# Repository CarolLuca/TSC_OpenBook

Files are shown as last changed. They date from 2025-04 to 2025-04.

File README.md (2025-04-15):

# OpenBook

## Introduction

OpenBook is an energy-efficient e-book reader designed with open-source principles, featuring Wi-Fi connectivity and environmental sensing capabilities. The device emphasizes a minimalist design, providing a distraction-free reading experience through a high-contrast e-paper display that mimics real paper, reducing eye strain during extended reading sessions.

## Block Diagram

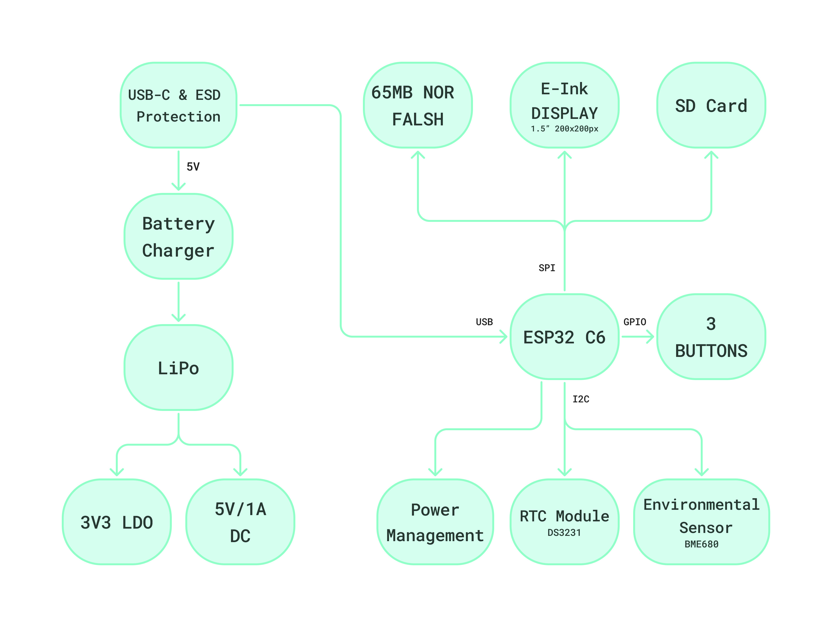
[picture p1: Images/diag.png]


## Hardware Description

### Microcontroller

The OpenBook is built around the **ESP32-C6-WROOM-1-N8** microcontroller:
- 32-bit RISC-V single-core processor running at up to 160MHz
- 320KB ROM, 512KB HP SRAM, 16KB LP SRAM
- Built-in Wi-Fi 6 and Bluetooth LE 5.0 connectivity
- Support for various interfaces: GPIO, SPI, UART, I2C, PWM
- Operating voltage: 3.3V

The ESP32-C6 offers excellent power efficiency with multiple power modes:
- Active mode: 160-260mA (when running at full capacity)
- Modem sleep: 3-20mA (Wi-Fi radio disabled)
- Light sleep: 0.8mA
- Deep sleep: 10μA (core powered down, wake sources active)
- Hibernation: 2.5μA (minimal functions active)

### Display Interface

The OpenBook connects to a 7.5" E-Paper Display through an FPC connector. The display communicates via SPI:
- EPD_CS connected to ESP32-C6 GPIO10
- EPD_DC connected to ESP32-C6 GPIO5
- EPD_RST connected to ESP32-C6 GPIO23
- EPD_BUSY connected to ESP32-C6 GPIO3
- MOSI, SCK shared with SD card interface

The e-paper display was chosen for its paper-like appearance, ultra-low power consumption (only requires power during page refreshes), and excellent readability in direct sunlight.

### Storage Solutions

The OpenBook features dual storage solutions:

1. **MicroSD Card Interface** (primary storage for e-books):
   - Connected via SPI protocol
   - Card Detect/DAT3 connected to ESP32-C6 GPIO4
   - CMD connected to ESP32-C6 GPIO7 (MOSI for SPI)
   - DAT0 connected to ESP32-C6 GPIO2 (MISO for SPI)
   - CLK connected to ESP32-C6 GPIO6 (SCK for SPI)
   
2. **64MB NOR Flash Memory** (firmware and system storage):
   - Connected via SPI protocol
   - CS connected to ESP32-C6 GPIO11
   - Shares MOSI, MISO, and SCK with the SD card interface
   - Provides reliable non-volatile storage for the operating system and application code

### Real-Time Clock (RTC)

A DS3231SN RTC module maintains accurate timekeeping even when the device is powered off:
- Communicates via I2C protocol
- SCL connected to ESP32-C6 GPIO22
- SDA connected to ESP32-C6 GPIO21
- Reset pin connected to ESP32-C6 GPIO18
- 32KHz output connected to ESP32-C6 GPIO1
- SQW/INT connected to ESP32-C6 GPIO0
- Features a backup battery input for continuous timekeeping
- Temperature-compensated crystal oscillator for high accuracy (+/-2ppm)

### Environmental Sensing

The BME688 environmental sensor provides comprehensive monitoring:
- Digital low-power gas, pressure, temperature, and humidity sensor
- Communicates via I2C (shared bus with RTC)
- SCK connected to ESP32-C6 GPIO22 (SCL for I2C)
- SDI connected to ESP32-C6 GPIO21 (SDA for I2C)
- Control pins connected to ESP32-C6 GPIO19
- Power consumption: 3.7μA at 1Hz sampling rate; 0.15μA in sleep mode
- Temperature range: -40 to +85°C
- Humidity measurement range: 0-100% RH
- Pressure range: 300-1100 hPa

### Power Management

The OpenBook is designed for extended battery life:

1. **USB-C Connector**:
   - Industry-standard charging and data interface
   - Connected to ESP32-C6 via USB lines (GPIO12/GPIO13)
   - ESD protection provided by USBLC6-2SC6Y
   
2. **Li-Po Battery Charging Controller (MCP73831)**:
   - Handles battery charging from USB with programmable charge current
   - Input voltage: 3.75V to 6V
   - Battery output protection circuitry

3. **LDO Voltage Regulator (XC6220A331MR-G)**:
   - Provides stable 3.3V from battery voltage
   - Low quiescent current: 1μA
   - High efficiency operation

4. **Battery Fuel Gauge (MAX17048G+T10)**:
   - Monitors battery charge level using ModelGauge algorithm
   - Communicates via I2C (shared bus with RTC and BME688)
   - SCL connected to ESP32-C6 GPIO22
   - SDA connected to ESP32-C6 GPIO21
   - Power consumption: 23μA active, 3μA hibernate
   - Provides accurate remaining capacity estimation

### User Input

Three physical buttons provide intuitive navigation:
1. **Reset Button**: Connected to ESP32-C6 Enable pin
2. **Boot Button**: Connected to ESP32-C6 GPIO9
3. **Navigation Button**: Connected to ESP32-C6 GPIO15

Each button includes debouncing circuitry to ensure reliable operation.

### Expansion Capability

A Qwiic connector provides expandability:
- Compatible with Stemma QT sensors and modules
- Connects to the I2C bus
- Allows for easy addition of future sensors without soldering

## Pin Allocation of ESP32-C6

| Pin Number | GPIO | Function | Component | Reason for Selection |
|---|---|---|---|---|
| 3 | EN | Reset | Reset Button | Hardware-defined enable pin |
| 8 | GPIO0 | SQW/INT | RTC DS3231SN Interrupt | Allows RTC-based wakeup from sleep |
| 9 | GPIO1 | 32KHz input | RTC DS3231SN 32KHz output | Provides precise timing reference |
| 27 | GPIO2 | MISO | SD Card, E-Paper, NOR Flash | Hardware SPI MISO line |
| 28 | GPIO3 | EPD_BUSY | E-Paper Display busy signal | Status monitoring for display |
| 30 | GPIO4 | SD_CS | SD Card chip select | SPI device selection |
| 31 | GPIO5 | EPD_DC | E-Paper Display data/command | Display controller communication |
| 32 | GPIO6 | SCK | SD Card, E-Paper, NOR Flash | Hardware SPI clock |
| 33 | GPIO7 | MOSI | SD Card, E-Paper, NOR Flash | Hardware SPI MOSI line |
| 13 | GPIO9 | Boot | Boot Button | Boot mode selection |
| 14 | GPIO10 | EPD_CS | E-Paper Display chip select | SPI device selection |
| 15 | GPIO11 | FLASH_CS | NOR Flash chip select | SPI device selection |
| 16 | GPIO12 | USB_D- | USB Data negative | USB communication |
| 17 | GPIO13 | USB_D+ | USB Data positive | USB communication |
| 23 | GPIO15 | Navigation | Navigation Button | User input |
| 16 | GPIO18 | RTC_RST | RTC reset | Reset control for RTC |
| 17 | GPIO19 | I2C_PW | BME688 power control | Power management for sensor |
| 19 | GPIO21 | SDA | I2C data (RTC, BME688, Battery Gauge) | Hardware I2C data line |
| 20 | GPIO22 | SCL | I2C clock (RTC, BME688, Battery Gauge)| Hardware I2C clock line |
| 21 | GPIO23 | EPD_RST | E-Paper Display reset | Display initialization control |

## Bill of Materials (BOM)

| Component | Description | Price (EUR) | Provider | Datasheet |
|---|---|---|---|---|
| ESP32-C6-WROOM-1-N8 | Main Microcontroller | 2.99 | [Mouser](https://eu.mouser.com/ProductDetail/Espressif-Systems/ESP32-C6-WROOM-1U-N8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) | [Datasheet](https://eu.mouser.com/datasheet/2/891/Espressif_Systems_7_11_2023_esp32_c6_wroom_1_wroom-3236277.pdf) |
| USB4110-GF-A | USB-C Connector | 0.39 | [Mouser](https://eu.mouser.com/ProductDetail/Same-Sky/UJC-H-G-SMT-2-P6-TR?qs=IKkN%2F947nfApFV8T6rOqww%3D%3D) | [Datasheet](https://eu.mouser.com/datasheet/2/1628/ujc_h_g_smt_2_p6_tr-3511211.pdf) |
| USBLC6-2SC6Y | USB ESD Protection | 0.44 | [Mouser](https://eu.mouser.com/ProductDetail/STMicroelectronics/USBLC6-2SC6Y?qs=gNDSiZmRJS%2FOgDexvXkdow%3D%3D) | [Datasheet](https://eu.mouser.com/datasheet/2/389/usblc6_2sc6y-1852505.pdf) |
| DMG2305UX-7 | P-Channel MOSFET | 0.19 × 2 | [Mouser](https://eu.mouser.com/ProductDetail/Diodes-Incorporated/DMG2305UX-7?qs=L1DZKBg7t5F%2FNBHrjfxC%252Bg%3D%3D) | [Datasheet](https://www.diodes.com/assets/Datasheets/DMG2305UX.pdf) |
| SD0805S020S1R0 | Schottky Diode | 0.30 × 2 | [Mouser](https://eu.mouser.com/ProductDetail/KYOCERA-AVX/SD0805S020S1R0?qs=jCA%252BPfw4LHbpkAoSnwrdjw%3D%3D) | [Datasheet](https://eu.mouser.com/datasheet/2/40/schottky-3165252.pdf) |
| XC6220A331MR-G | LDO Voltage Regulator | 1.46 | [Mouser](https://eu.mouser.com/ProductDetail/Torex-Semiconductor/XC6220A331MR-G?qs=AsjdqWjXhJ8ZSWznL1J0gg%3D%3D) | [Datasheet](https://eu.mouser.com/datasheet/2/760/xc6220-3371556.pdf) |
| 293D107X9010D2TE3 | Tantalum Capacitor | 0.68 | [Mouser](https://eu.mouser.com/ProductDetail/Vishay-Sprague/293D107X9010D2TE3?qs=8dfOI6wKXonVqFgS8%252BQ%2FMA%3D%3D) | [Datasheet](https://www.vishay.com/docs/40002/293d.pdf) |
| 112A-TAAR-R03 | MicroSD Card Socket | 1.10 | [Comet](https://store.comet.srl.ro/Catalogue/Product/43497/) | [Datasheet](https://store.comet.bg/download-file.php?id=27596) |
| IFDC5050JZER680M | 68µH Power Inductor | 0.90 | [Mouser](https://eu.mouser.com/ProductDetail/Vishay-Dale/IFDC5050JZER680M?qs=iLKYxzqNS745SePZd8tBoA%3D%3D) | [Datasheet](https://www.vishay.com/docs/34635/ifdc5050jz.pdf) |
| MBR0530-TP | Schottky Diode | 0.14 × 3 | [Mouser](https://eu.mouser.com/ProductDetail/Micro-Commercial-Components-MCC/MBR0530-TP?qs=KFo7JewZbUECRHkxGanrdg%3D%3D) | [Datasheet](https://eu.mouser.com/datasheet/2/258/MBR0520_MBR0580_SOD123_-2492194.pdf) |
| SI1308EDL-T1-GE3 | N-Channel MOSFET | 0.42 × 2 | [Mouser](https://eu.mouser.com/ProductDetail/Vishay-Semiconductors/SI1308EDL-T1-GE3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) | [Datasheet](https://www.vishay.com/docs/63399/si1308edl.pdf) |
| KGF21BR71H104KT | 0.1µF Capacitor | 0.30 | [Mouser](https://eu.mouser.com/ProductDetail/KYOCERA-AVX/KGF21BR71H104KT?qs=Jm2GQyTW%2FbjYyKCvVWAEOw%3D%3D) | [Datasheet](https://eu.mouser.com/datasheet/2/40/KGF-3223650.pdf) |
| MAASL105CC7105MFCA01 | 1µF Capacitor | 0.13 × 10 | [Mouser](https://eu.mouser.com/ProductDetail/TAIYO-YUDEN/MAASL105CC7105MFCA01?qs=HFfMDpzxxd1Fn%2FInbJA7vw%3D%3D) | [Datasheet](https://eu.mouser.com/datasheet/2/396/TAIYO_YUDEN_04_27_2024_c_mlcc_A_e1-3451516.pdf) |
| CM05X5R475M16AH | 4.7µF Capacitor | 0.23 × 5 | [Mouser](https://eu.mouser.com/ProductDetail/KYOCERA-AVX/CM05X5R475M16AH?qs=doiCPypUmgFT1xquZKhWtQ%3D%3D) | [Datasheet](https://eu.mouser.com/datasheet/2/40/Kyocera_AVX_Components_CM025_CM05_CM105_CM21_E217K-2932876.pdf) |
| CGA3EDX7T1A106M080AU | 10µF Capacitor | 0.47 | [Mouser](https://eu.mouser.com/ProductDetail/TDK/CGA3EDX7T1A106M080AU?qs=ZcfC38r4PovL%2FBNBUzzBFw%3D%3D) | [Datasheet](https://product.tdk.com/system/files/dam/doc/product/capacitor/ceramic/mlcc/catalog/mlcc_automotive_general_en.pdf) |
| KAM21BR71H104JT | 100nF Capacitor | 0.30 × 8 | [Mouser](https://eu.mouser.com/ProductDetail/KYOCERA-AVX/KAM21BR71H104JT?qs=Jm2GQyTW%2Fbic6Zk4McEt6w%3D%3D) | [Datasheet](https://eu.mouser.com/datasheet/2/40/AutoMLCCKAM-3216307.pdf) |
| RNCL1210FT50L0 | 0.47Ω Resistor | 0.30 | [Mouser](https://eu.mouser.com/ProductDetail/SEI-Stackpole/RNCL1210FT50L0?qs=17ckDYBRdelVLOJ%252BDFjlUw%3D%3D) | [Datasheet](https://eu.mouser.com/datasheet/2/385/sei_rncl-3223524.pdf) |
| RT1206FRE072R2L | 2.2Ω Resistor | 0.13 | [Mouser](https://eu.mouser.com/ProductDetail/YAGEO/RT1206FRE072R2L?qs=XhSZopxZ3H6S0nYZD83pAA%3D%3D) | [Datasheet](https://eu.mouser.com/datasheet/2/447/PYu_RT_1_to_0_01_RoHS_L_15-3461507.pdf) |
| ERA-6AHD150V | 15Ω Resistor | 0.25 | [Mouser](https://eu.mouser.com/ProductDetail/Panasonic/ERA-6AHD150V?qs=MNPzkKEzRtQip8ZeekU%252BRw%3D%3D) | [Datasheet](https://industrial.panasonic.com/cdbs/www-data/pdf/RDM0000/AOA0000C307.pdf) |
| RP73C2B200RFTDF | 200Ω Resistor | 0.33 | [Mouser](https://eu.mouser.com/ProductDetail/TE-Connectivity-Holsworthy/RP73C2B200RFTDF?qs=n4i9pByFsMR0dWGpf721CA%3D%3D) | [Datasheet](https://eu.mouser.com/datasheet/2/418/10/ENG_DS_1773272_M1-1588495.pdf) |
| ERA-3AED202V | 2kΩ Resistor | 0.16 | [Mouser](https://eu.mouser.com/ProductDetail/Panasonic/ERA-3AED202V?qs=yocZuyCaXdM2cBmjcGkIyA%3D%3D) | [Datasheet](https://industrial.panasonic.com/cdbs/www-data/pdf/RDM0000/AOA0000C307.pdf) |
| MCS04020C5101FE000 | 5.1kΩ Resistor | 0.15 × 2 | [Mouser](https://eu.mouser.com/ProductDetail/Vishay-Beyschlag/MCS04020C5101FE000?qs=wTZ%2FFzl837YsKPLPRIXUbg%3D%3D) | [Datasheet](https://www.vishay.com/docs/28705/mcx0x0xpro.pdf) |
| RNWA0612BTE10K0 | 10kΩ Resistor | 0.32 × 16 | [Mouser](https://eu.mouser.com/ProductDetail/SEI-Stackpole/RNWA0612BTE10K0?qs=IKkN%2F947nfD62pDKWE9ZTQ%3D%3D) | [Datasheet](https://eu.mouser.com/datasheet/2/385/SEI_RNWA-3473840.pdf) |
| ERA-3AED104V | 100kΩ Resistor | 0.10 | [Mouser](https://eu.mouser.com/ProductDetail/Panasonic/ERA-3AED104V?qs=MNPzkKEzRtQIWcmUWL4kjg%3D%3D) | [Datasheet](https://industrial.panasonic.com/cdbs/www-data/pdf/RDM0000/AOA0000C307.pdf) |
| MCP73831-2ACI-MC | Li-Po Battery Charging Controller | 0.75 | [Mouser](https://eu.mouser.com/ProductDetail/Microchip-Technology/MCP73831-2ACI-MC?qs=hH%252BOa0VZEiBneYTVdpuVdg%3D%3D) | [Datasheet](https://eu.mouser.com/datasheet/2/268/MCP73831_Family_Data_Sheet_DS20001984H-3441711.pdf) |
| FH34SRJ-24S-0.5SH(99) | FPC Connector for E-Paper | 2.60 | [Mouser](https://eu.mouser.com/ProductDetail/Hirose-Connector/FH34SRJ-24S-0.5SH99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) | [Datasheet](https://eu.mouser.com/datasheet/2/185/FH34SRJ_24S_0_5SH_99__CL0580_1255_6_99_2DDrawing_0-1615044.pdf) |
| BME688 | Environmental Sensor | 9.86 | [Mouser](https://eu.mouser.com/ProductDetail/Bosch-Sensortec/BME688?qs=IS%252B4QmGtzzqQoVDscqwx3A%3D%3D) | [Datasheet](https://eu.mouser.com/datasheet/2/783/bst_bme688_fl000-2307034.pdf) |
| BD5229G-TR | Voltage Detector | 0.75 | [Mouser](https://eu.mouser.com/ProductDetail/ROHM-Semiconductor/BD5229G-TR?qs=4kLU8WoGk0vvnhrrYwdszw%3D%3D) | [Datasheet](https://fscdn.rohm.com/en/products/databook/datasheet/ic/power/voltage_detector/bd52xxg-e.pdf)  |
| MAX17048G+T10 | Battery Fuel Gauge | 4.28 | [Mouser](https://eu.mouser.com/ProductDetail/Analog-Devices-Maxim-Integrated/MAX17048G%2bT10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) | [Datasheet](https://eu.mouser.com/datasheet/2/609/MAX17048_MAX17049-3469099.pdf) |
| DS3231SN# | RTC Module | 14.91 | [Mouser](https://eu.mouser.com/ProductDetail/Analog-Devices-Maxim-Integrated/DS3231SN?qs=1eQvB6Dk1vhUlr8%2FOrV0Fw%3D%3D) | [Datasheet](https://eu.mouser.com/datasheet/2/609/DS3231-3421123.pdf) |
| CPH3225A | RTC Backup Battery | 2.33 | [Mouser](https://eu.mouser.com/ProductDetail/Seiko-Semiconductors/CPH3225A?qs=3etwrb1wR%252BhUOph6lAO7eg%3D%3D) | [Datasheet](https://eu.mouser.com/datasheet/2/360/Seiko_Instruments_MicroBattery_E_20230330_2024Jan_-3561061.pdf) |
| PRT-14417 | Qwiic Connector | 3.75 | [Mouser](https://eu.mouser.com/ProductDetail/Adafruit/4208?qs=PzGy0jfpSMtbScLbr0L5dw%3D%3D) | [Datasheet](https://learn.adafruit.com/introducing-adafruit-stemma-qt/technical-specs) |
| PGB1010603MR | ESD Protection | 0.40 × 6 | [Mouser](https://eu.mouser.com/ProductDetail/Littelfuse/PGB1010603MR?qs=gu7KAQ731URLg4GSnNNN7Q%3D%3D) | [Datasheet](https://www.littelfuse.com/assetdocs/pulseguard-esd-suppressors-pgb1-datasheet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) |
| W25Q512JVEIQ | 64MB NOR Flash Memory | 5.84 | [Mouser](https://eu.mouser.com/ProductDetail/Winbond/W25Q512JVEIQ?qs=l7cgNqFNU1jw6svr3at6tA%3D%3D) | [Datasheet](https://eu.mouser.com/datasheet/2/949/Winbond_W25Q512JV_Datasheet-3240039.pdf) |
| LP584174 | 2500mAh Li-Po Battery | 6.40 | [TME](https://www.tme.eu/en/details/accu-lp584174_cl/rechargeable-batteries/cellevia-batteries/l584174/) | [Datasheet](https://www.tme.eu/Document/e0683d8c34e6d878124489f71bffb6ee/cel0014.pdf) |
| MT-DEPG0750BNU590F1 | 7.5" E-Paper Display | 48.00 | [Mouser](https://eu.mouser.com/ProductDetail/Microtips-Technology/MT-DEPG0750BNU590F1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) | [Datasheet](https://eu.mouser.com/datasheet/2/271/MT_DEPG0750BNU590F1_V2_7-1894282.pdf) |

## Power Consumption Analysis

The OpenBook is designed for maximum battery efficiency:

1. **Peak Power Mode** (Wi-Fi active, display refreshing):
   - ESP32-C6: 160-260mA
   - E-Paper (during refresh): 20-50mA
   - SD Card (active): 30-100mA
   - Other components: ~20-30mA
   - **Total peak consumption**: ~230-440mA

2. **Active Reading Mode** (Wi-Fi disabled, display static):
   - ESP32-C6 (Modem sleep): 3-20mA
   - E-Paper (static): ~0mA
   - SD Card (periodic access): ~5mA average
   - Other components: ~5-10mA
   - **Total active consumption**: ~13-35mA

3. **Standby Mode** (waiting for input):
   - ESP32-C6 (Light sleep): 0.8mA
   - All peripherals in low-power: ~1mA
   - **Total standby consumption**: ~1.8mA

4. **Deep Sleep Mode** (longer periods of inactivity):
   - ESP32-C6 (Deep sleep): 10μA
   - RTC active: 0.2μA
   - Battery monitoring (periodic): ~0.5μA average
   - **Total deep sleep consumption**: ~11μA

With a 2500mAh battery, theoretical runtime estimates:
- Continuous active reading: ~71-192 hours (3-8 days)
- Standby mode: ~1388 hours (~58 days)
- Deep sleep mode: ~227,272 hours (~9,469 days or ~26 years)

In practical usage with mixed operation modes and periodic Wi-Fi synchronization, users can expect 2-4 weeks of regular

Note: props to the Gemini within Google Drawings for helping me with the drawing:)

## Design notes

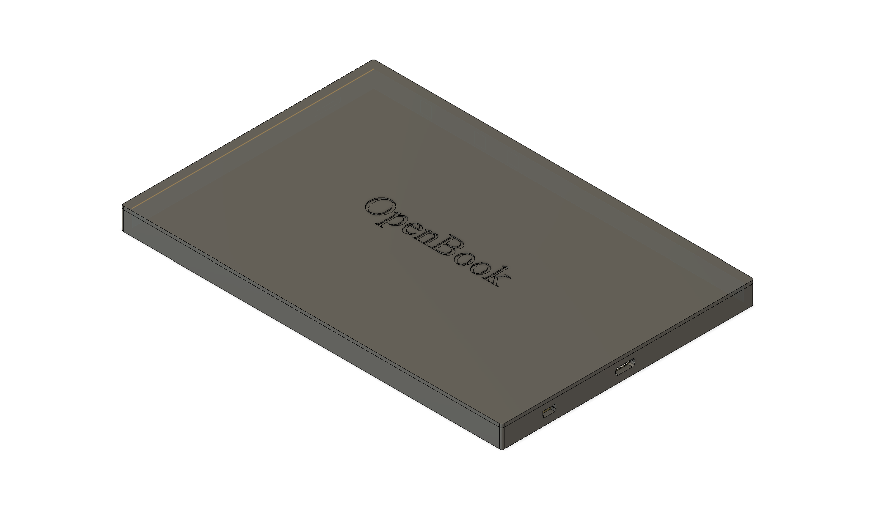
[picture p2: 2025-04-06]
Images/basic-product.png

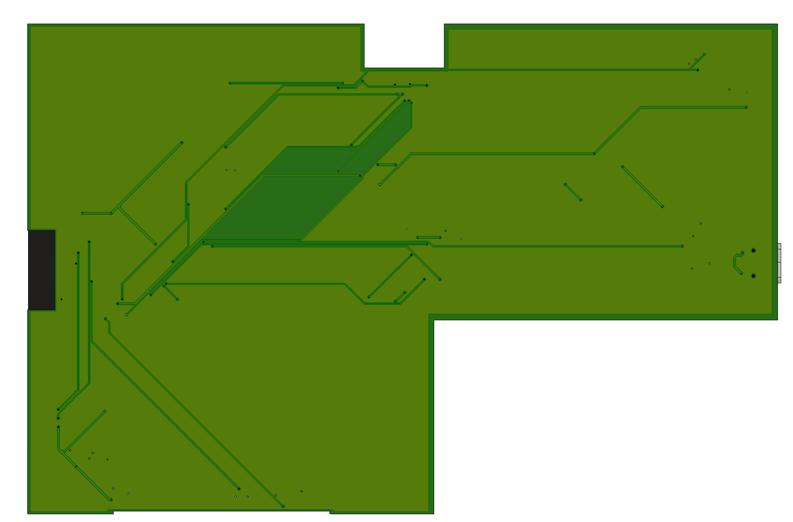
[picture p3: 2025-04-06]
Images/bottom-3d.png

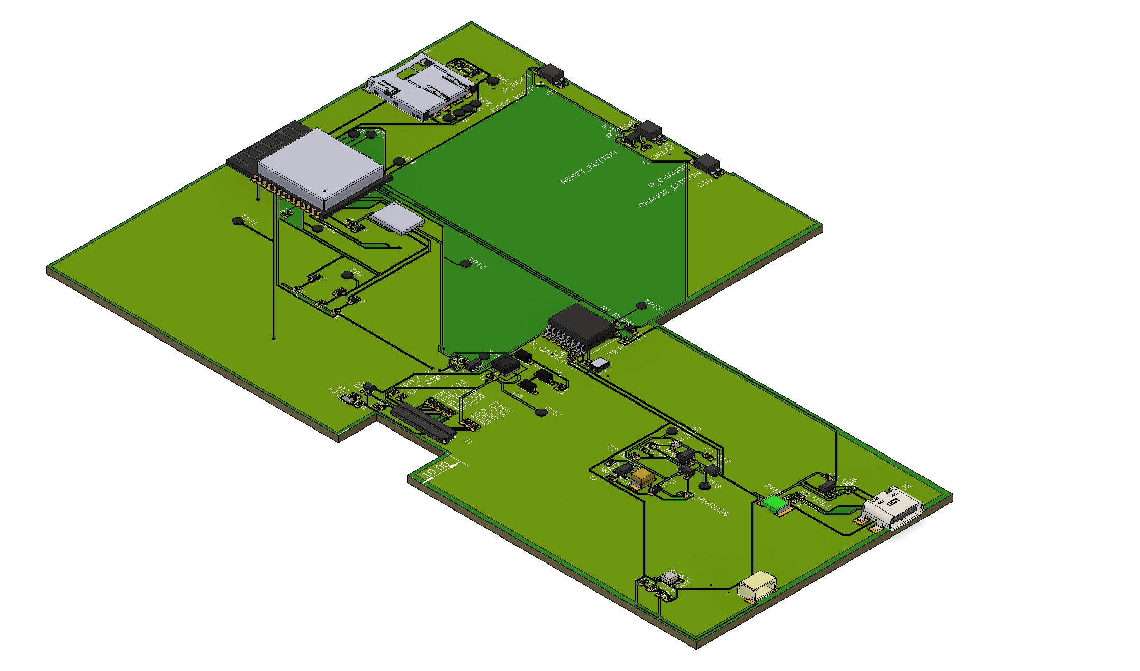
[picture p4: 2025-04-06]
Images/basic-3d.png

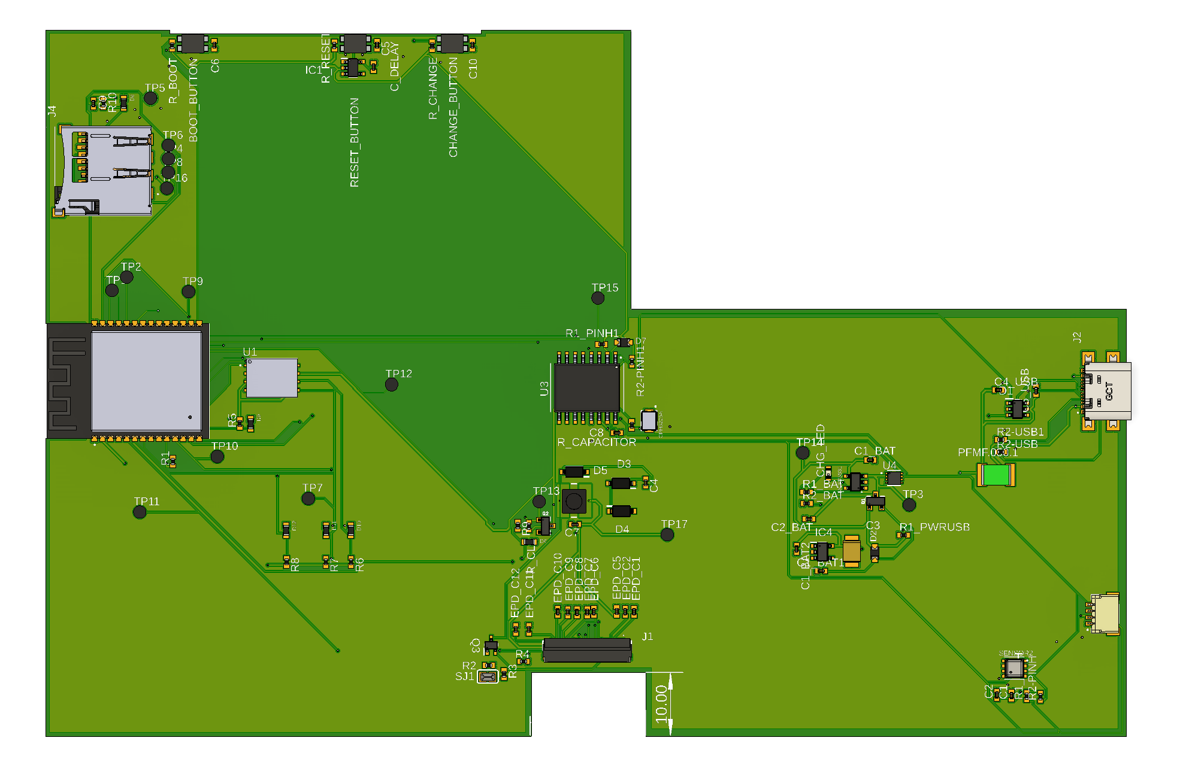
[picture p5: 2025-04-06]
Images/top-3d.png

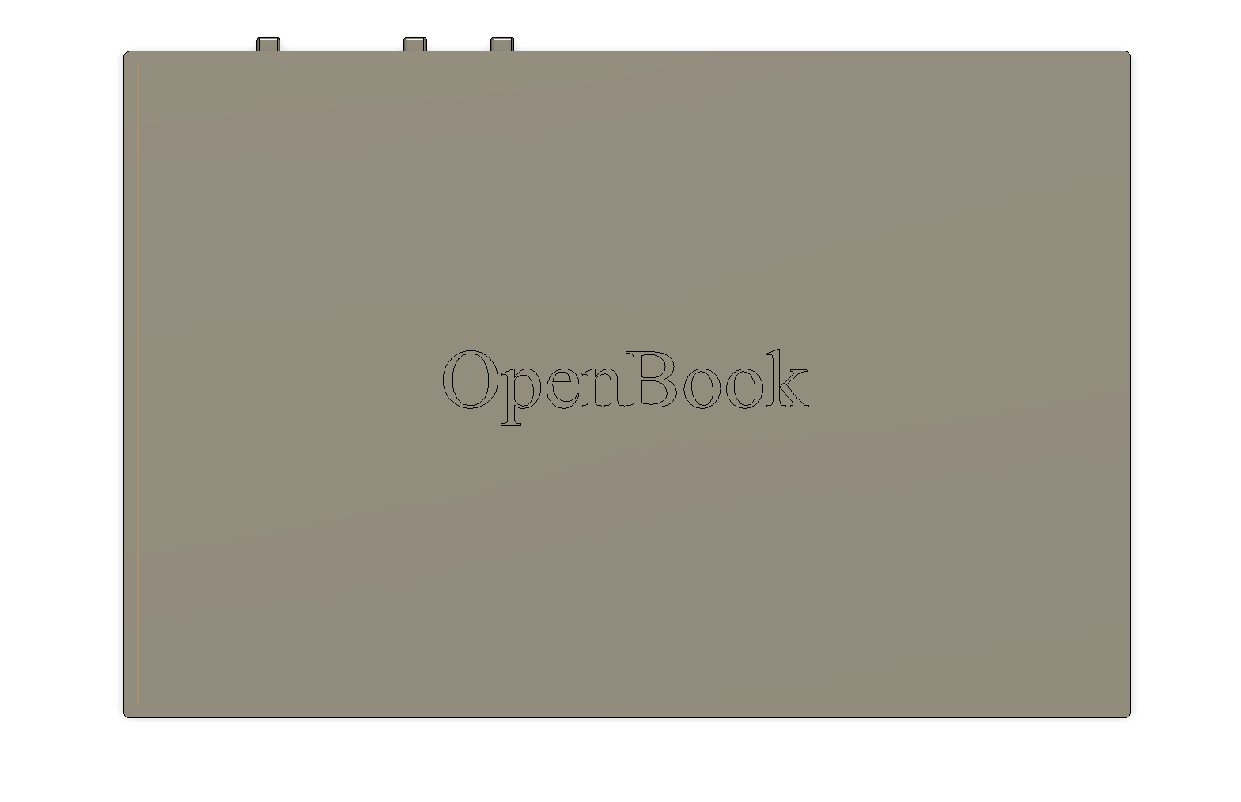
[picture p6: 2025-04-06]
Images/top-product.png

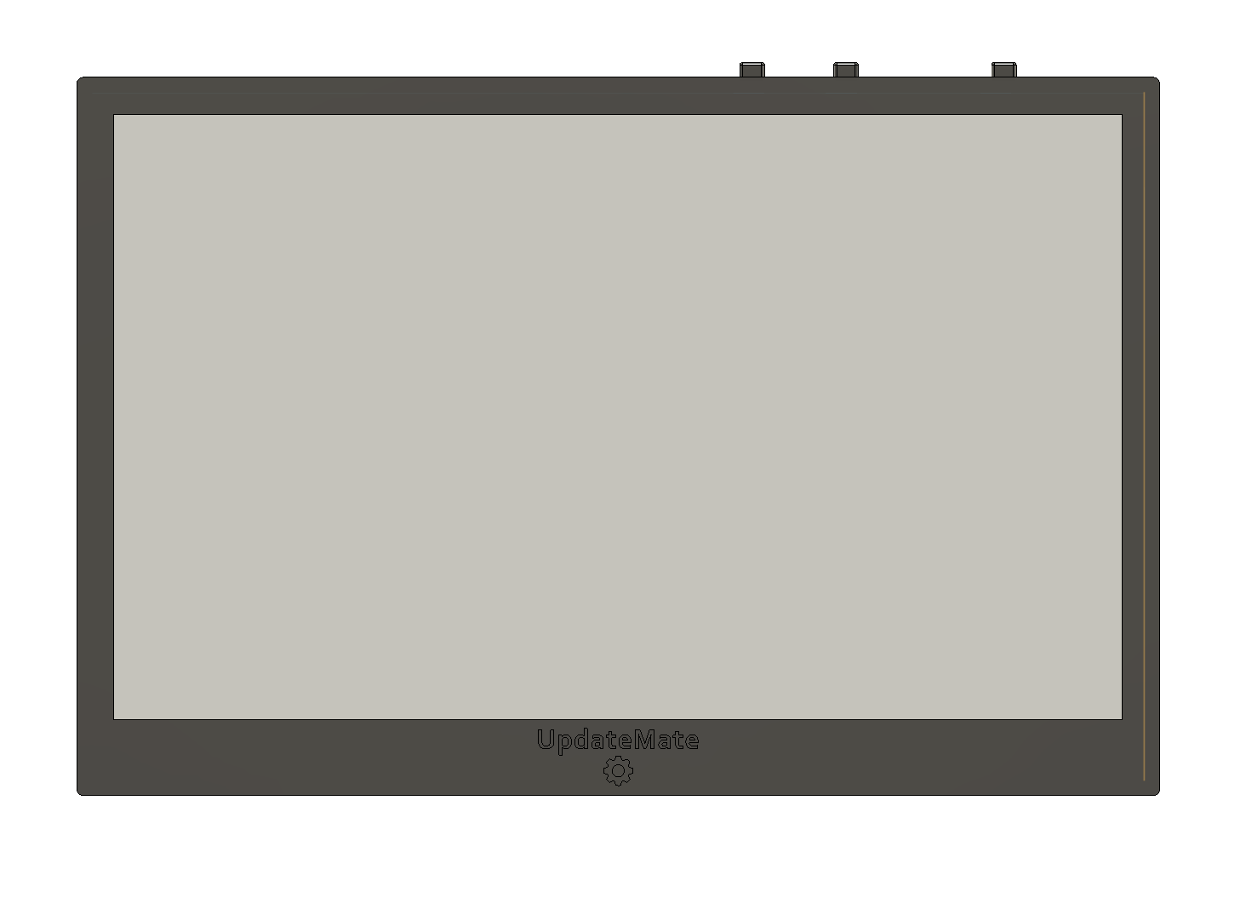
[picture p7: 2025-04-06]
Images/bottom-product.png

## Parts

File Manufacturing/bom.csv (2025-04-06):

Qty | Value | Device | Package | Parts | Description | ARROW_PART_NUMBER | ARROW_PRICE-STOCK | AVAILABILITY | CENTROID_NOT_SPECIFIED | CHECK_PRICES | COPYRIGHT | DATASHEET | DESCRIPTION | DIGIKEY_DESCRIPTION | DIGIKEY_PART_NUMBER | HEIGHT | LEAD_FREE | MANUFACTURER_NAME | MANUFACTURER_PART_NUMBER | MF | MFR_NAME | MOUSER_PART_NUMBER | MOUSER_PRICE-STOCK | MOUSER_TESTING_PART_NUMBER | MOUSER_TESTING_PRICE-STOCK | MP | MPN | PACKAGE | POPULARITY | PREFIX | PRICE | PROD_ID | PURCHASE-URL | ROHS | SNAPEDA_LINK | SPICEMODEL | SPICEPREFIX | TEMPERATURE_RANGE_HIGH | TEMPERATURE_RANGE_LOW | TP_SIGNAL_NAME | VALUE
1 |  | ADAFRUIT_LEDCHIP-LED0603 | ADAFRUIT_CHIP-LED0603 | CHG_LED | LED
1 |  | SJ | SJ | SJ1 | SMD solder JUMPER |  |  |  |  |  |  |  |  |  |  |  |  |  |  |  |  |  |  |  |  |  |  |  | 3
1 | 0.1uF/50V | ESP32_WROVER_EAGLE-LTSPICE_CC0402 | ESP32_WROVER_EAGLE-LTSPICE_C0402 | EPD_C5 | CAPACITOR, European symbol |  |  |  |  |  |  |  |  |  |  |  |  |  |  |  |  |  |  |  |  |  |  |  |  |  |  |  |  |  |  | NONE | C
1 | 0.47 | ESP32_WROVER_EAGLE-LTSPICE_RR0402 | ESP32_WROVER_EAGLE-LTSPICE_R0402 | R3 | RESISTOR, European symbol |  |  |  |  |  |  |  |  |  |  |  |  |  |  |  |  |  |  |  |  |  |  |  |  |  |  |  |  |  |  | NONE | R
1 | 100k | ESP32_WROVER_EAGLE-LTSPICE_RR0402 | ESP32_WROVER_EAGLE-LTSPICE_R0402 | R1_PWRUSB | RESISTOR, European symbol |  |  |  |  |  |  |  |  |  |  |  |  |  |  |  |  |  |  |  |  |  |  |  |  |  |  |  |  |  |  | NONE | R
8 | 100nF | ESP32_WROVER_EAGLE-LTSPICE_CC0402 | ESP32_WROVER_EAGLE-LTSPICE_C0402 | C1, C2, C4_USB, C6, C8, C9, C10, C_DELAY | CAPACITOR, European symbol |  |  |  |  |  |  |  |  |  |  |  |  |  |  |  |  |  |  |  |  |  |  |  |  |  |  |  |  |  |  | NONE | C
1 | 100uF TANT | RCL_CPOL-EUCT3528 | RCL_CT3528 | C3 | POLARIZED CAPACITOR, European symbol |  |  |  |  |  |  |  |  |  |  |  |  |  |  |  |  |  |  |  |  |  |  |  | 0 |  |  |  |  |  |  |  | C
16 | 10k | ESP32_WROVER_EAGLE-LTSPICE_RR0402 | ESP32_WROVER_EAGLE-LTSPICE_R0402 | R1, R1_PINH, R1_PINH1, R2-PINH, R2-PINH1, R4, R5, R6, R7, R8, R9, R10, R_BOOT, R_CHANGE, R_CL1, R_RESET | RESISTOR, European symbol |  |  |  |  |  |  |  |  |  |  |  |  |  |  |  |  |  |  |  |  |  |  |  |  |  |  |  |  |  |  | NONE | R
1 | 10uF | ESP32_WROVER_EAGLE-LTSPICE_CC0402 | ESP32_WROVER_EAGLE-LTSPICE_C0402 | C7 | CAPACITOR, European symbol |  |  |  |  |  |  |  |  |  |  |  |  |  |  |  |  |  |  |  |  |  |  |  |  |  |  |  |  |  |  | NONE | C
1 | 112A-TAAR-R03_ATTEND | 112A-TAAR-R03_ATTEND | 112ATAARR03ATTEND | J4 | Micro SD Card Socket, Push-Push Type, Top Mount, SMT, H=1.83mm, 10u |  |  |  |  |  |  |  | Micro SD Card Socket | Push-Push Type | Top Mount | SMT | H=1.83mm | 10u |  |  | 1.9mm |  | ATTEND | 112A-TAAR-R03 ATTEND
1 | 15 | ESP32_WROVER_EAGLE-LTSPICE_RR0402 | ESP32_WROVER_EAGLE-LTSPICE_R0402 | R_CAPACITOR | RESISTOR, European symbol |  |  |  |  |  |  |  |  |  |  |  |  |  |  |  |  |  |  |  |  |  |  |  |  |  |  |  |  |  |  | NONE | R
1 | 1nF | ESP32_WROVER_EAGLE-LTSPICE_CC0402 | ESP32_WROVER_EAGLE-LTSPICE_C0402 | C5 | CAPACITOR, European symbol |  |  |  |  |  |  |  |  |  |  |  |  |  |  |  |  |  |  |  |  |  |  |  |  |  |  |  |  |  |  | NONE | C
9 | 1uF/50V | ESP32_WROVER_EAGLE-LTSPICE_CC0402 | ESP32_WROVER_EAGLE-LTSPICE_C0402 | EPD_C1, EPD_C2, EPD_C6, EPD_C7, EPD_C8, EPD_C9, EPD_C10, EPD_C11, EPD_C12 | CAPACITOR, European symbol |  |  |  |  |  |  |  |  |  |  |  |  |  |  |  |  |  |  |  |  |  |  |  |  |  |  |  |  |  |  | NONE | C
1 | 2.2 | ESP32_WROVER_EAGLE-LTSPICE_RR0402 | ESP32_WROVER_EAGLE-LTSPICE_R0402 | R2 | RESISTOR, European symbol |  |  |  |  |  |  |  |  |  |  |  |  |  |  |  |  |  |  |  |  |  |  |  |  |  |  |  |  |  |  | NONE | R
1 | 200 | ESP32_WROVER_EAGLE-LTSPICE_RR0402 | ESP32_WROVER_EAGLE-LTSPICE_R0402 | R1_BAT | RESISTOR, European symbol |  |  |  |  |  |  |  |  |  |  |  |  |  |  |  |  |  |  |  |  |  |  |  |  |  |  |  |  |  |  | NONE | R
2 | 20V/4.2A/52mO/1.4W | ESP32_WROVER_SPARKFUN-DISCRETESEMI_MOSFET_PCH-DMG2305UX-7 | ESP32_WROVER_SPARKFUN-DISCRETESEMI_SOT23-3 | Q1, Q2 | P-channel MOSFETs |  |  |  |  |  |  |  |  |  |  |  |  |  |  |  |  |  |  |  |  |  |  |  |  |  |  | TRAN-14388 |  |  |  |  |  |  |  |  | 20V/4.2A/52mO/1.4W
1 | 2K | ESP32_WROVER_EAGLE-LTSPICE_RR0402 | ESP32_WROVER_EAGLE-LTSPICE_R0402 | R2_BAT | RESISTOR, European symbol |  |  |  |  |  |  |  |  |  |  |  |  |  |  |  |  |  |  |  |  |  |  |  |  |  |  |  |  |  |  | NONE | R
5 | 4.7uF | ESP32_WROVER_EAGLE-LTSPICE_CC0402 | ESP32_WROVER_EAGLE-LTSPICE_C0402 | C1_BAT, C1_BAT1, C1_BAT2, C2_BAT, C5_USB | CAPACITOR, European symbol |  |  |  |  |  |  |  |  |  |  |  |  |  |  |  |  |  |  |  |  |  |  |  |  |  |  |  |  |  |  | NONE | C
1 | 4.7uF/25V | ESP32_WROVER_EAGLE-LTSPICE_CC0402 | ESP32_WROVER_EAGLE-LTSPICE_C0402 | C4 | CAPACITOR, European symbol |  |  |  |  |  |  |  |  |  |  |  |  |  |  |  |  |  |  |  |  |  |  |  |  |  |  |  |  |  |  | NONE | C
2 | 5k1 | ESP32_WROVER_EAGLE-LTSPICE_RR0402 | ESP32_WROVER_EAGLE-LTSPICE_R0402 | R2-USB, R2-USB1 | RESISTOR, European symbol |  |  |  |  |  |  |  |  |  |  |  |  |  |  |  |  |  |  |  |  |  |  |  |  |  |  |  |  |  |  | NONE | R
1 | 68uH | 744043680IND_4828-WE-TPC_WRE | IND_4828-WE-TPC_WRE | L1 |  |  |  |  |  |  | Copyright (C) 2024 Ultra Librarian. All rights reserved. |  |  |  |  |  |  |  | 744043680 |  | Wurth Electronics
1 | BD5229G-TR | BD5229G-TR | SOT95P280X125-5N | IC1 | Voltage Detector with Adjustable Delay Time: CMOS processes are utilized to develop high precision, low current consumption CMOS reset ICs that allow arbitrary setting of the delay time. The extensive lineup includes both Nch Open Drain and CMOS output types in a wide range of detection voltages (from 2.3V to 6.0V, in 0.1V steps), enabling selection of the ideal solution based on customer requirements. In addition, the entire series is of course both lead-free and RoHS-compliant. |  |  |  |  |  |  |  | Voltage Detector with Adjustable Delay Time: CMOS processes are utilized to develop high precision | low current consumption CMOS reset ICs that allow arbitrary setting of the delay time. The extensive lineup includes both Nch Open Drain and CMOS output types in a wide range of detection voltages (from 2.3V to 6.0V | in 0.1V steps) | enabling selection of the ideal solution based on customer requirements. In addition | the entire series is of course both lead-free and RoHS-compliant. |  |  | 1.25mm |  | ROHM Semiconductor | BD5229G-TR |  |  | 755-BD5229G-TR | https://www.mouser.co.uk/ProductDetail/ROHM-Semiconductor/BD5229G-TR?qs=4kLU8WoGk0vvnhrrYwdszw%3D%3D
3 | BUTTON_CUSYOMV1 | BUTTON_CUSYOMV1 | MYBUTTON | BOOT_BUTTON, CHANGE_BUTTON, RESET_BUTTON
1 | CPH3225A | CPH3225A | CAPCP3225X100N | CPH3225A | Cap 0.011F 3.3V 1210 Flat Check availability |  |  | Not in stock |  | https://www.snapeda.com/parts/CPH3225A/Seiko+Instruments/view-part/?ref=eda |  |  | 11 mF (EDLC) Supercapacitor 3.3 V 1210 (3225 Metric) - - |  |  |  |  |  |  | Seiko Instruments |  |  |  |  |  | CPH3225A |  | 1210 Seiko |  |  | None |  | https://www.snapeda.com/api/url_track_click_mouser/?unipart_id=562593&manufacturer=Seiko Instruments&part_name=CPH3225A&search_term=None |  | https://www.snapeda.com/parts/CPH3225A/Seiko+Instruments/view-part/?ref=snap
1 | DS3231SN# | DS3231SN# | SOIC127P1032X265-16N | U3 | Real Time Clock Serial 16-Pin SOIC W T/R Check availability |  |  | In Stock |  | https://www.snapeda.com/parts/DS3231SN%23/Analog+Devices/view-part/?ref=eda |  |  | Extremely Accurate I²C-Integrated RTC/TCXO/Crystal |  |  |  |  |  |  | Analog Devices |  |  |  |  |  | DS3231SN# |  | SOIC-16 Maxim |  |  | None |  | https://www.snapeda.com/api/url_track_click_mouser/?unipart_id=99048&manufacturer=Analog Devices&part_name=DS3231SN#&search_term=None |  | https://www.snapeda.com/parts/DS3231SN%23/Analog+Devices/view-part/?ref=snap
1 | ESP32-C6-WROOM-1-N8 | ESP32-C6-WROOM-1-N8 | XCVR_ESP32-C6-WROOM-1-N8 | U2 | Check availability |  |  | In Stock |  | https://www.snapeda.com/parts/ESP32-C6-WROOM-1-N8/Espressif+Systems/view-part/?ref=eda |  |  | Multiprotocol Modules ESP32-C6 module | Wi-Fi 6 in 2.4 GHz band | Bluetooth 5 | Zigbee 3.0 and Thread. ESP34-WROOM Compatible - ENGINEERING SAMPLE |  |  |  |  |  |  | Espressif Systems |  |  |  |  |  | ESP32-C6-WROOM-1-N8 |  | None |  |  | None |  |  |  | https://www.snapeda.com/parts/ESP32-C6-WROOM-1-N8/Espressif+Systems/view-part/?ref=snap
1 | ESP32C6_VARISTORCN1812 | ESP32C6_VARISTORCN1812 | ESP32C6_VARISTOR_CT/CN1812 | PFMF.050.1 | VARISTOR |  |  |  |  |  |  |  |  |  |  |  |  |  |  |  |  |  |  |  |  |  |  |  | 0
2 | ESP32_WROVER_AVX---SD0805S020S1R0_AVX_SD0805S020S1R0_0_0AVX_SD0805S020S1R0_0_0 | ESP32_WROVER_AVX---SD0805S020S1R0_AVX_SD0805S020S1R0_0_0AVX_SD0805S020S1R0_0_0 | ESP32_WROVER_AVX---SD0805S020S1R0_AVX_SD0805S020S1R0_0 | D2, D7 | Schottky Barrier Rectifier Diode |  |  |  | No |  |  | http://datasheets.avx.com/schottky.pdf |  | DIODE SCHOTTKY 20V 1A 0805 | 478-7800-1-ND |  | yes |  |  | AVX |  | 581-SD0805S020S1R0 |  |  |  |  |  | 0805 (2012 metric) |  | D |  |  |  | yes |  |  |  | +125°C | -55°C
1 | ESP32_WROVER_BME680_BME680 | ESP32_WROVER_BME680_BME680 | ESP32_WROVER_BME680_PSON80P300X300X100-8N | SENSOR2 | Integrated Environmental Unit |  |  | Unavailable |  |  |  |  | Integrated Environmental Unit |  |  |  |  |  |  | Bosch Sensortec |  |  |  |  |  | BME680 |  | LGA-8 Bosch Tools |  |  | None
1 | ESP32_WROVER_SPARKFUN-IC-POWER_MCP73831 | ESP32_WROVER_SPARKFUN-IC-POWER_MCP73831 | ESP32_WROVER_SPARKFUN-IC-POWER_SOT23-5 | MCP73831 | MCP73831T Li-Ion, Li-Pol Controller |  |  |  |  |  |  |  |  |  |  |  |  |  |  |  |  |  |  |  |  |  |  |  |  |  |  | IC-09995
1 | FH34SRJ-24S-0.5SH_99_ | FH34SRJ-24S-0.5SH_99_ | FH34SRJ24S05SH99 | J1 | (0.50mm) Surface Mount, Right Angle |  |  |  |  |  |  |  | 24 Position FFC | FPC Connector Contacts | (0.50mm) Surface Mount | Right Angle |  |  | 1.1mm |  | Hirose | FH34SRJ-24S-0.5SH(99) |  |  | 798-FH34SRJ24S05SH99 | https://www.mouser.co.uk/ProductDetail/Hirose-Connector/FH34SRJ-24S-0.5SH99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
1 | MAX17048G+T10 | MAX17048G+T10 | SON50P200X200X80-9N | U4 | Check availability |  |  | In Stock |  | https://www.snapeda.com/parts/MAX17048G+T10/Analog+Devices/view-part/?ref=eda |  |  | 3µA 1-Cell/2-Cell Fuel Gauge with ModelGauge |  |  |  |  |  |  | Analog Devices |  |  |  |  |  | MAX17048G+T10 |  | TDFN-8 Maxim |  |  | None |  | https://www.snapeda.com/api/url_track_click_mouser/?unipart_id=329239&manufacturer=Analog Devices&part_name=MAX17048G+T10&search_term=None |  | https://www.snapeda.com/parts/MAX17048G+T10/Analog+Devices/view-part/?ref=snap
3 | MBR0530 | MBR0530 | SOD3716X135N | D3, D4, D5 | ON SEMICONDUCTOR - MBR0530 - DIODE, SCHOTTKY, 0.5A, 30V, SOD-123 |  |  | In Stock |  | https://www.snapeda.com/parts/MBR0530/Onsemi/view-part/?ref=eda |  |  | Diode Schottky 30 V 500mA Surface Mount SOD-123 |  |  |  |  |  |  | ON Semiconductor |  |  |  |  |  | MBR0530 |  | SOD-123-2 ON Semiconductor |  |  | None |  | https://www.snapeda.com/api/url_track_click_mouser/?unipart_id=179458&manufacturer=ON Semiconductor&part_name=MBR0530&search_term=None |  | https://www.snapeda.com/parts/MBR0530/Onsemi/view-part/?ref=snap
6 | PGB1010603MR | PGB1010603MR | DIOC1608X36N | D6, D8, D9, D10, D11, D12 | Check availability |  |  | In Stock |  | https://www.snapeda.com/parts/PGB1010603MR/Littelfuse/view-part/?ref=eda |  |  | 150V (Typ) Clamp - Ipp Tvs Diode Surface Mount 0603 (1608 Metric) |  |  |  |  |  |  | Littelfuse Inc. |  |  |  |  |  | PGB1010603MR |  | 0603 Littelfuse Inc. |  |  | None |  | https://www.snapeda.com/api/url_track_click_mouser/?unipart_id=5659453&manufacturer=Littelfuse Inc.&part_name=PGB1010603MR&search_term=None |  | https://www.snapeda.com/parts/PGB1010603MR/Littelfuse/view-part/?ref=snap
1 | QWIIC_RIGHT_ANGLE | QWIIC_CONNECTORJS-1MM | JST04_1MM_RA | J3 | SparkFun I2C Standard Qwiic Connector |  |  |  |  |  |  |  |  |  |  |  |  |  |  |  |  |  |  |  |  |  |  |  |  |  |  | CONN-13694 |  |  |  |  |  |  |  |  | QWIIC_RIGHT_ANGLE
1 | SAMACSYS_PARTS_USB4110-GF-A | SAMACSYS_PARTS_USB4110-GF-A | SAMACSYS_PARTS_USB4110GFA | J2 | CONN USB 2.0 TYPE-C R/A SMT |  |  |  |  |  |  |  | CONN USB 2.0 TYPE-C R/A SMT |  |  | 3.26mm |  | GCT (GLOBAL CONNECTOR TECHNOLOGY) | USB4110-GF-A |  |  | 640-USB4110-GF-A | https://www.mouser.co.uk/ProductDetail/GCT/USB4110-GF-A?qs=KUoIvG%2F9IlYiZvIXQjyJeA%3D%3D
1 | SI1308EDL-T1-GE3 | SI1308EDL-T1-GE3 | SOT65P210X110-3N | Q3 | MOSFET N-Ch 30V 1.5A TrenchFET SC70 Vishay Si1308EDL-T1-GE3 N-channel MOSFET Transistor, 1.5 A, 30 V, 3-Pin SC-70 |  |  | In Stock |  | https://www.snapeda.com/parts/SI1308EDL-T1-GE3/Vishay+Siliconix/view-part/?ref=eda |  |  | Si1308EDL-T1-GE3 N-channel MOSFET Transistor | 1.5 A | 30 V | 3-Pin SC-70 | Siliconix / Vishay SI1308EDL-T1-GE3 |  |  |  |  |  |  | Vishay Siliconix |  |  |  |  |  | SI1308EDL-T1-GE3 |  | SOT-323 Vishay Semiconductor |  |  | None |  | https://www.snapeda.com/api/url_track_click_mouser/?unipart_id=274603&manufacturer=Vishay Siliconix&part_name=SI1308EDL-T1-GE3&search_term=None |  | https://www.snapeda.com/parts/SI1308EDL-T1-GE3/Vishay+Siliconix/view-part/?ref=snap
17 | TPTP20R | TPTP20R | TP20R | TP1, TP2, TP3, TP4, TP5, TP6, TP7, TP8, TP9, TP10, TP11, TP12, TP13, TP14, TP15, TP16, TP17 | Test pad |  |  |  |  |  |  |  |  |  |  |  |  |  |  |  |  |  |  |  |  |  |  |  | 2
1 | USBLC6-2SC6Y | USBLC6-2SC6Y | SOT95P280X145-6N | D1 | Low Cap. ESD Protection Auto SOT-23-6 STMicroelectronics USBLC6-2SC6Y, Dual Uni-Directional TVS Diode Array, 6-Pin SOT-23 |  |  | In Stock |  | https://www.snapeda.com/parts/USBLC6-2SC6Y/STMicroelectronics/view-part/?ref=eda |  |  | 17V Clamp 5A (8/20µs) Ipp Tvs Diode Surface Mount SOT-23-6 |  |  |  |  |  |  | STMicroelectronics |  |  |  |  |  | USBLC6-2SC6Y |  | SOT-23-6 STMicroelectronics |  |  | None |  |  |  | https://www.snapeda.com/parts/USBLC6-2SC6Y/STMicroelectronics/view-part/?ref=snap
1 | W25Q512JVEIQ | W25Q512JVEIQ | SON127P600X800X80-9N | U1 | Check availability |  |  | In Stock |  | https://www.snapeda.com/parts/W25Q512JVEIQ/Winbond+Electronics/view-part/?ref=eda |  |  | FLASH - NOR Memory IC 512Mb (64M x 8) SPI - Quad I/O 133 MHz 8-WSON (8x6) |  |  |  |  |  |  | Winbond Electronics |  |  |  |  |  | W25Q512JVEIQ |  | Package |  |  | None |  |  |  | https://www.snapeda.com/parts/W25Q512JVEIQ/Winbond+Electronics/view-part/?ref=snap
1 | XC6220A331MR-G | XC6220A331MR-G | SOT95P280X120-5N | IC4 | LDO Voltage Regulators |  |  |  |  |  |  |  | LDO Voltage Regulators |  |  | 1.2mm |  | Torex | XC6220A331MR-G |  |  | 865-XC6220A331MR-G | https://www.mouser.co.uk/ProductDetail/Torex-Semiconductor/XC6220A331MR-G?qs=AsjdqWjXhJ8ZSWznL1J0gg%3D%3D

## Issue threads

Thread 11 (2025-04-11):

[3D] Butoanele sunt puse gresit pe carcasa

shefancodeman, 2025-04-11:
# Description

- exista spatiu gol lasat intre cover-ul de butoane si carcasa

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

# Suggestion

- putem muta butoanele la loc sau le putem extinde

CarolLuca, 2025-04-14:
Fixed. Nu stiu cum le-am stricat in prima instanta:)

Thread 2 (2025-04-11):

[3D] Nume nesugestiv al modelului placii

shefancodeman, 2025-04-11:
# Description

- la download, numele pcb-ului 3d devine "buttons"
- nu pare o problema grava

# Suggestion

- poti schimba numele modelului 3d

CarolLuca, 2025-04-14:
Done.

Closed 2025-04-14.

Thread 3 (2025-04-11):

[PCB] 4 erori mici copper-width

shefancodeman, 2025-04-11:
# Description

- exista 4 erori usor de ratat la componentele L1 si U4 (ignorand inevitabilele SMD hole errors)

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

# Suggestion

- nu par erori ce pot strica tot design-ul, pot fi rezolvate cu un routing diferit

CarolLuca, 2025-04-14:
Done. Trebuie modificata dimensiunea la pad-uri.

Closed 2025-04-14.

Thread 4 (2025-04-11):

[PCB] Grosimea pcb-ului nu este cea recomandata

shefancodeman, 2025-04-11:
# Description

- board-ul are grosimea de 1.67mm in loc de cel de 1mm recomandat

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

# Suggestion

- desi in cazul asta (si in al meu) board-ul se potrivea la fel de bine si cu 1.6mm, ar trebui modificat pentru a corespunde sugestiei profesorului

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

- putem face asta din fisierul pcb-ului, intrand pe Design -> Layers -> Layers stack (din scroll-down)

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

CarolLuca, 2025-04-14:
FIxed. Am modificat la 1mm.

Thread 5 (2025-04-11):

[PCB] Traseul contine 3 unghiuri drepte

shefancodeman, 2025-04-11:
# Description

- traseul este 90% corect, dar contine 3 unghiuri drepte:

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

# Suggestion

- acestea pot fi modificate cu un route manual

CarolLuca, 2025-04-14:
Fixed. Le-am modificat peste tot.

Closed 2025-04-14.

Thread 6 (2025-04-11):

[PCB] Butoanele nu sunt centrate

shefancodeman, 2025-04-11:
# Description

- pozitian butoanelor nu coincide exact cu masuratorile facute
- acest lucru poate fi intentionat, pentru a coincide cu butoanele de pe carcasa, de aceea nu adaug sugestie pana nu imi este clarificat

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

CarolLuca, 2025-04-14:
Fixed. Le-am mutat la locul potrivit.

Closed 2025-04-14.

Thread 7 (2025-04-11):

[PCB] Pare ca o masuratoare este eronata

shefancodeman, 2025-04-11:
# Description

- dimensiunea spatiului taiat pentru montarea mufei ecranului pare mai mica cu 0.17 mm

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

# Suggestion

- ar trebui masurata si taiata acea fanta din nou

CarolLuca, 2025-04-14:
Fixed. Am taiat corespunzator dupa marcajul facut.

Closed 2025-04-14.

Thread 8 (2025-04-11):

[PCB] Masuratorile nu sunt pe layer-ul corect

shefancodeman, 2025-04-11:
# Description

- masuratorile apar pe layer-ul 21, in loc de 47

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

# Suggestion

- acestea pot fi schimbat pe layer-ul 47 din Properties -> Layers

CarolLuca, 2025-04-14:
Fixed. Le-am pus pe layer-ul corect.

Closed 2025-04-14.

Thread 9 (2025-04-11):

[PCB] Suprapuneri pe silkscreen

shefancodeman, 2025-04-11:
# Description

- numele unor componente se suprapun pe silkscreen

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

# Suggestion

- trebuie doar mutate/rotite aceste denumiri

CarolLuca, 2025-04-14:
Fixed. Le-am aranjat corespunzator.

Closed 2025-04-14.

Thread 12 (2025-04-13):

[Documentație] Diagrama nu respectă formatul cerut

dantudose, 2025-04-13:
Diagrama text cu cuprinde toate detaliile legate de semnale, magistrale de comunicație și componente folosite în proiect. Verifică recomandarea de diagramă pe care v-am dat-o, pentru referință.

CarolLuca, 2025-04-14:
Fixed. Am modificat diagrama conform precizarilor.

Closed 2025-04-14.

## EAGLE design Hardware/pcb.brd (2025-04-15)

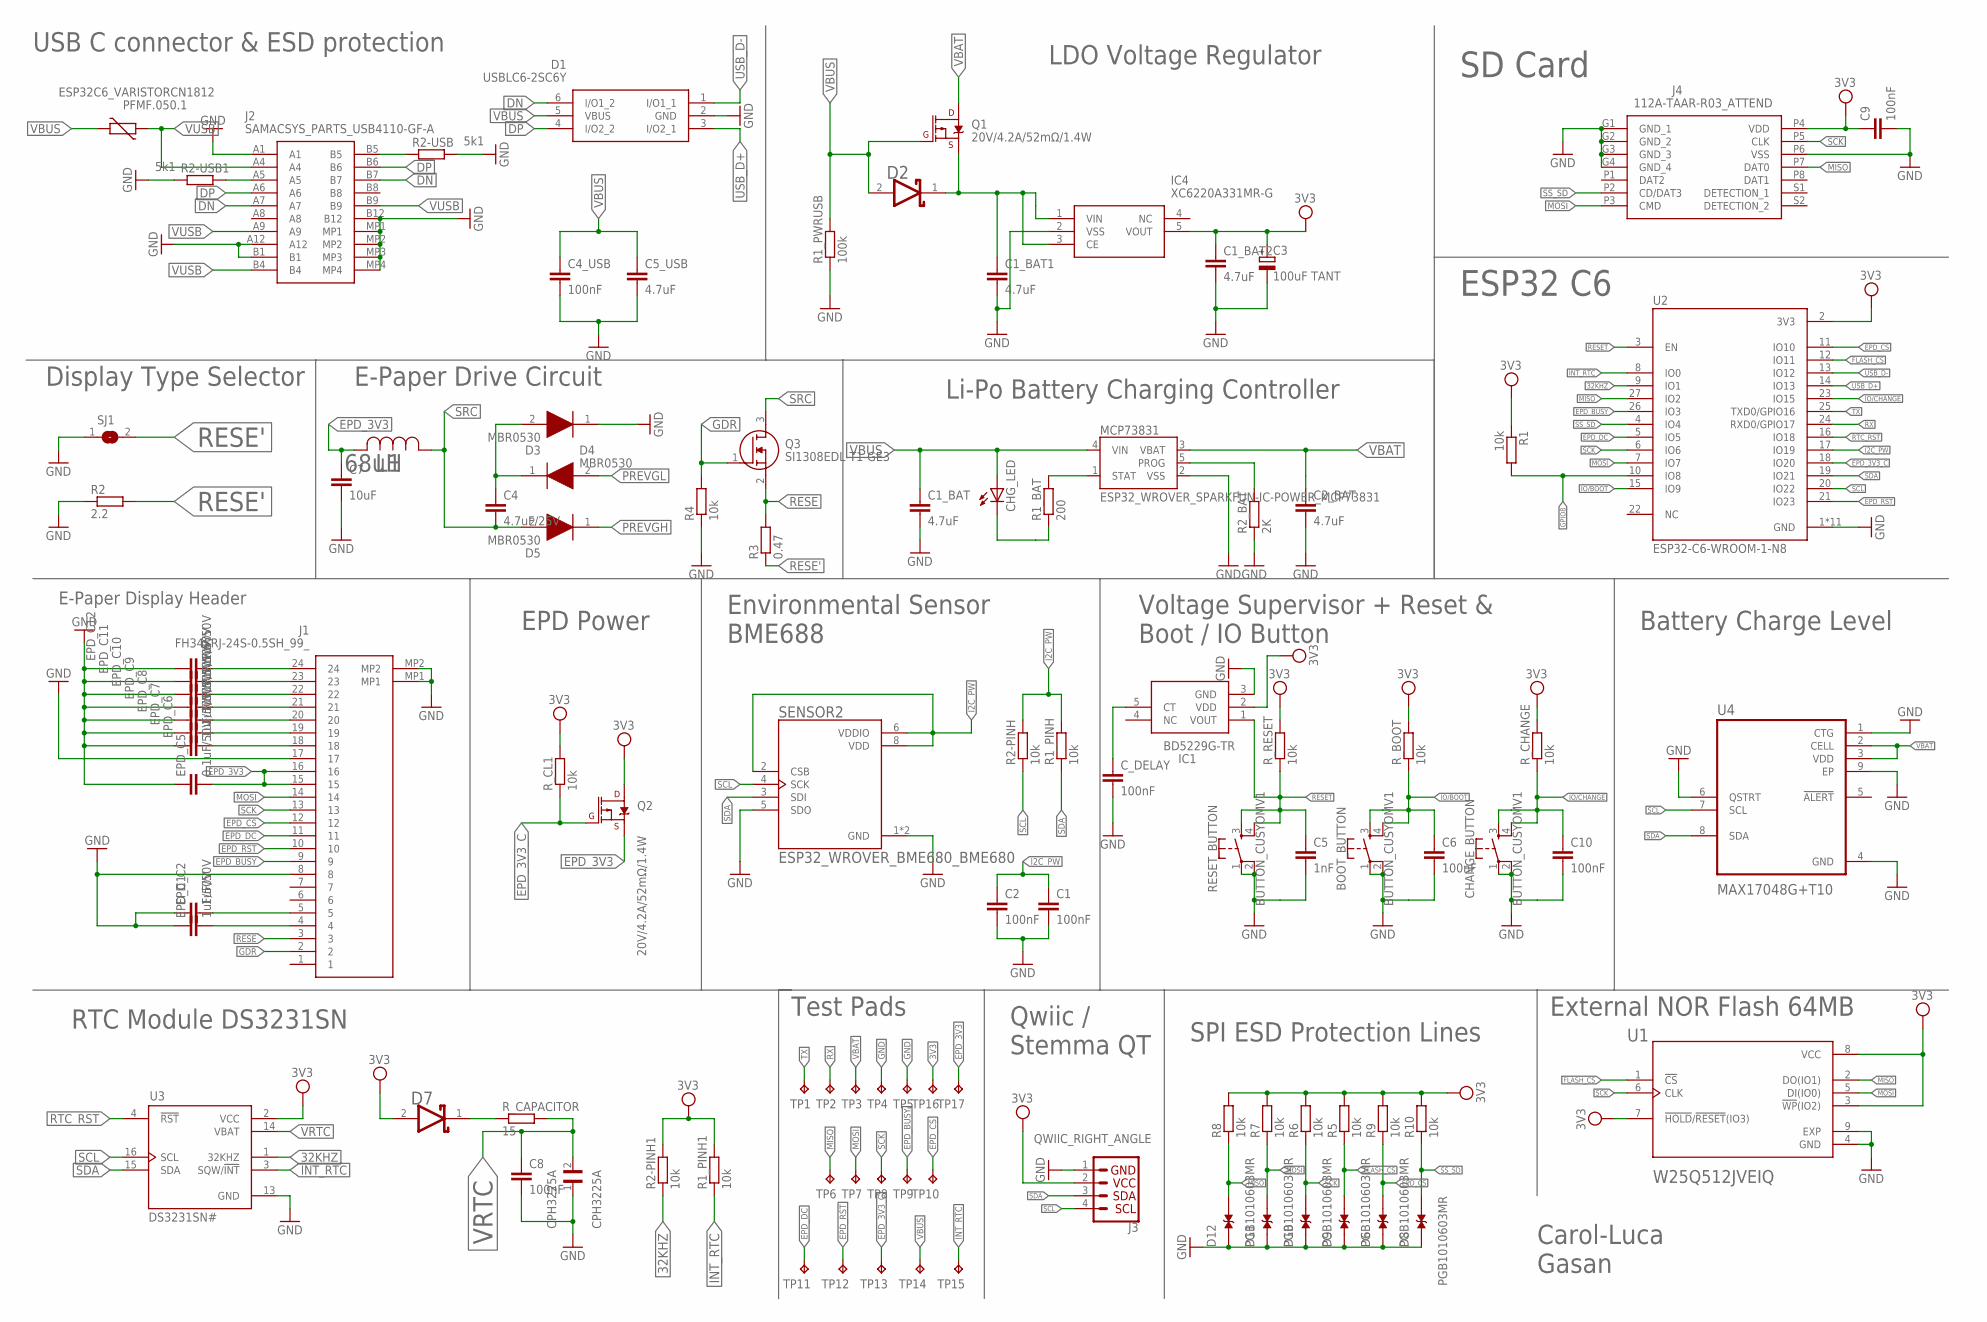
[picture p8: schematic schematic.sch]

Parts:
BOOT_BUTTON: BUTTON_CUSYOMV1; MYBUTTON
C1, C2, C4_USB, C6, C8, C9, C10: 100nF; ESP32_WROVER_EAGLE-LTSPICE_C0402
C1_BAT, C1_BAT1, C1_BAT2, C2_BAT, C5_USB: 4.7uF; ESP32_WROVER_EAGLE-LTSPICE_C0402
C3: 100uF TANT; RCL_CT3528
C4: 4.7uF/25V; ESP32_WROVER_EAGLE-LTSPICE_C0402
C5: 1nF; ESP32_WROVER_EAGLE-LTSPICE_C0402
C7: 10uF; ESP32_WROVER_EAGLE-LTSPICE_C0402
CHANGE_BUTTON: BUTTON_CUSYOMV1; MYBUTTON
CHG_LED: ADAFRUIT_LEDCHIP-LED0603; ADAFRUIT_CHIP-LED0603
CPH3225A: CPH3225A; CAPCP3225X100N
C_DELAY: 100nF; ESP32_WROVER_EAGLE-LTSPICE_C0402
D1: USBLC6-2SC6Y; SOT95P280X145-6N
D2, D7: ESP32_WROVER_AVX---SD0805S020S1R0_AVX_SD0805S020S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; ESP32_WROVER_AVX---SD0805S020S1R0_AVX_SD0805S020S1R0_0
D3, D4, D5: MBR0530; SOD3716X135N
D6, D8, D9, D10, D11, D12: PGB1010603MR; DIOC1608X36N
EPD_C1, EPD_C2, EPD_C6, EPD_C7, EPD_C8, EPD_C9, EPD_C10, EPD_C11, EPD_C12: 1uF/50V; ESP32_WROVER_EAGLE-LTSPICE_C0402
EPD_C5: 0.1uF/50V; ESP32_WROVER_EAGLE-LTSPICE_C0402
IC1: BD5229G-TR; SOT95P280X125-5N
IC4: XC6220A331MR-G; SOT95P280X120-5N
J1: FH34SRJ-24S-0.5SH_99_; FH34SRJ24S05SH99
J2: SAMACSYS_PARTS_USB4110-GF-A; SAMACSYS_PARTS_USB4110GFA
J3: QWIIC_RIGHT_ANGLE; JST04_1MM_RA
J4: 112A-TAAR-R03_ATTEND; 112ATAARR03ATTEND
L1: 68uH; IND_4828-WE-TPC_WRE
MCP73831: ESP32_WROVER_SPARKFUN-IC-POWER_MCP73831; ESP32_WROVER_SPARKFUN-IC-POWER_SOT23-5
PFMF.050.1: ESP32C6_VARISTORCN1812; ESP32C6_VARISTOR_CT/CN1812
Q1, Q2: 20V/4.2A/52mΩ/1.4W; ESP32_WROVER_SPARKFUN-DISCRETESEMI_SOT23-3
Q3: SI1308EDL-T1-GE3; SOT65P210X110-3N
R1, R1_PINH, R1_PINH1, R2-PINH, R2-PINH1, R4, R5, R6, R7, R8, R9, R10: 10k; ESP32_WROVER_EAGLE-LTSPICE_R0402
R1_BAT: 200; ESP32_WROVER_EAGLE-LTSPICE_R0402
R1_PWRUSB: 100k; ESP32_WROVER_EAGLE-LTSPICE_R0402
R2: 2.2; ESP32_WROVER_EAGLE-LTSPICE_R0402
R2-USB, R2-USB1: 5k1; ESP32_WROVER_EAGLE-LTSPICE_R0402
R2_BAT: 2K; ESP32_WROVER_EAGLE-LTSPICE_R0402
R3: 0.47; ESP32_WROVER_EAGLE-LTSPICE_R0402
RESET_BUTTON: BUTTON_CUSYOMV1; MYBUTTON
R_BOOT: 10k; ESP32_WROVER_EAGLE-LTSPICE_R0402
R_CAPACITOR: 15; ESP32_WROVER_EAGLE-LTSPICE_R0402
R_CHANGE: 10k; ESP32_WROVER_EAGLE-LTSPICE_R0402
R_CL1: 10k; ESP32_WROVER_EAGLE-LTSPICE_R0402
R_RESET: 10k; ESP32_WROVER_EAGLE-LTSPICE_R0402
SENSOR2: ESP32_WROVER_BME680_BME680; ESP32_WROVER_BME680_PSON80P300X300X100-8N
SJ1: SJ
TP1, TP2, TP3, TP4, TP5, TP6, TP7, TP8, TP9, TP10, TP11, TP12, TP13, TP14, TP15, TP16, TP17: TPTP20R; TP20R
U1: W25Q512JVEIQ; SON127P600X800X80-9N
U2: ESP32-C6-WROOM-1-N8; XCVR_ESP32-C6-WROOM-1-N8
U3: DS3231SN#; SOIC127P1032X265-16N
U4: MAX17048G+T10; SON50P200X200X80-9N

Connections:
3V3: C1_BAT2.1, C3.+, C9.1, D7.2 (ANODE), IC1.2 (VDD), IC4.5 (VOUT), J3.2, J4.P4 (VDD), Q2.3 (D), R1.1, R1_PINH1.2, R2-PINH1.2, R5.2, R6.2, R7.2, R8.2, R9.2, R10.2, R_BOOT.2, R_CHANGE.2, R_CL1.2, R_RESET.2, TP16.TP, U1.3 (!WP!(IO2)), U1.7 (!HOLD!/!RESET!(IO3)), U1.8 (VCC), U2.2 (3V3), U3.2 (VCC)
32KHZ: R2-PINH1.1, U2.9 (IO1), U3.1 (32KHZ)
DN: D1.6 (I/O1_2), J2.A7, J2.B7
DP: D1.4 (I/O2_2), J2.A6, J2.B6
EPD_3V3: C7.1, EPD_C5.2, J1.15, J1.16, L1.2, Q2.2 (S), TP17.TP
EPD_3V3_C: Q2.1 (G), R_CL1.1, TP13.TP, U2.18 (IO20)
EPD_BUSY: J1.9, TP9.TP, U2.26 (IO3)
EPD_CS: D6.2, J1.12, R9.1, TP10.TP, U2.11 (IO10)
EPD_DC: J1.11, TP11.TP, U2.5 (IO5)
EPD_RST: J1.10, TP12.TP, U2.21 (IO23)
FLASH_CS: D9.2, R5.1, U1.1 (!CS), U2.12 (IO11)
GDR: J1.2, Q3.1 (G), R4.2
GND: BOOT_BUTTON.1, BOOT_BUTTON.2, C1.2, C1_BAT.2, C1_BAT1.2, C1_BAT2.2, C2.2, C2_BAT.2, C3.-, C4_USB.2, C5.2, C5_USB.2, C6.2, C7.2, C8.2, C9.2, C10.2, CHANGE_BUTTON.1, CHANGE_BUTTON.2, CPH3225A.1, C_DELAY.2, D1.2 (GND), D3.1 (K), D6.1, D8.1, D9.1, D10.1, D11.1, D12.1, EPD_C1.1, EPD_C2.1, EPD_C5.1, EPD_C6.1, EPD_C7.1, EPD_C8.1, EPD_C9.1, EPD_C10.1, EPD_C11.1, EPD_C12.1, IC1.3 (GND), IC4.2 (VSS), J1.8, J1.17, J1.MP1, J1.MP2, J2.A1, J2.A12, J2.B1, J2.B12, J2.MP1, J2.MP2, J2.MP3, J2.MP4, J3.1, J4.G1 (GND_1), J4.G2 (GND_2), J4.G3 (GND_3), J4.G4 (GND_4), J4.P6 (VSS), MCP73831.2 (VSS), R1_PWRUSB.1, R2.1, R2-USB.2, R2-USB1.1, R2_BAT.1, R4.1, RESET_BUTTON.1, RESET_BUTTON.2, SENSOR2.1 (GND), SENSOR2.5 (SDO), SENSOR2.7 (GND), SJ1.1, TP4.TP, TP5.TP, U1.4 (GND), U1.9 (EXP), U2.1 (GND), U2.28 (GND), U2.29_1 (GND), U2.29_2 (GND), U2.29_3 (GND), U2.29_4 (GND), U2.29_5 (GND), U2.29_6 (GND), U2.29_7 (GND), U2.29_8 (GND), U2.29_9 (GND), U3.13 (GND), U4.1 (CTG), U4.4 (GND), U4.6 (QSTRT), U4.9 (EP)
GPIO8: R1.2, U2.10 (IO8)
I2C_PW: C1.1, C2.1, R1_PINH.2, R2-PINH.2, SENSOR2.2 (CSB), SENSOR2.6 (VDDIO), SENSOR2.8 (VDD), U2.17 (IO19)
INT_RTC: R1_PINH1.1, TP15.TP, U2.8 (IO0), U3.3 (SQW/!INT)
IO/BOOT: BOOT_BUTTON.3, BOOT_BUTTON.4, C6.1, R_BOOT.1, U2.15 (IO9)
IO/CHANGE: C10.1, CHANGE_BUTTON.3, CHANGE_BUTTON.4, R_CHANGE.1, U2.23 (IO15)
MISO: D12.2, J4.P7 (DAT0), R8.1, TP6.TP, U1.2 (DO(IO1)), U2.27 (IO2)
MOSI: D11.2, J1.14, J4.P3 (CMD), R7.1, TP7.TP, U1.5 (DI(IO0)), U2.7 (IO7)
unnamed: J2.B5, R2-USB.1
unnamed: J2.A5, R2-USB1.2
unnamed: C1_BAT1.1, D2.1 (CATHODE), IC4.1 (VIN), IC4.3 (CE), Q1.2 (S)
unnamed: D7.1 (CATHODE), R_CAPACITOR.1
unnamed: MCP73831.5 (PROG), R2_BAT.2
unnamed: MCP73831.1 (STAT), R1_BAT.2
unnamed: CHG_LED.C, R1_BAT.1
unnamed: EPD_C1.2, J1.4
unnamed: EPD_C2.2, J1.5
unnamed: C_DELAY.1, IC1.5 (CT)
unnamed: C4.1, D3.2 (A), D4.1 (K)
unnamed: EPD_C6.2, J1.18
unnamed: EPD_C7.2, J1.19
unnamed: EPD_C8.2, J1.20
unnamed: EPD_C9.2, J1.21
unnamed: EPD_C10.2, J1.22
unnamed: EPD_C11.2, J1.23
unnamed: EPD_C12.2, J1.24
PREVGH: D5.1 (K)
PREVGL: D4.2 (A)
RESE: J1.3, Q3.2 (S), R3.2
RESE': R2.2, R3.1, SJ1.2
RESET: C5.1, IC1.1 (VOUT), RESET_BUTTON.3, RESET_BUTTON.4, R_RESET.1, U2.3 (EN)
RTC_RST: U2.16 (IO18), U3.4 (!RST)
RX: TP2.TP, U2.24 (RXD0/GPIO17)
SCK: D10.2, J1.13, J4.P5 (CLK), R6.1, TP8.TP, U1.6 (CLK), U2.6 (IO6)
SCL: J3.4, R2-PINH.1, SENSOR2.4 (SCK), U2.20 (IO22), U3.16 (SCL), U4.7 (SCL)
SDA: J3.3, R1_PINH.1, SENSOR2.3 (SDI), U2.19 (IO21), U3.15 (SDA), U4.8 (SDA)
SRC: C4.2, D5.2 (A), L1.1, Q3.3 (D)
SS_SD: D8.2, J4.P2 (CD/DAT3), R10.1, U2.4 (IO4)
TX: TP1.TP, U2.25 (TXD0/GPIO16)
USB_D+: D1.3 (I/O2_1), U2.14 (IO13)
USB_D-: D1.1 (I/O1_1), U2.13 (IO12)
VBAT: C2_BAT.1, MCP73831.3 (VBAT), Q1.3 (D), TP3.TP, U4.2 (CELL), U4.3 (VDD)
VBUS: C1_BAT.1, C4_USB.1, C5_USB.1, CHG_LED.A, D1.5 (VBUS), D2.2 (ANODE), MCP73831.4 (VIN), PFMF.050.1.2, Q1.1 (G), R1_PWRUSB.2, TP14.TP
VRTC: C8.1, CPH3225A.2, R_CAPACITOR.2, U3.14 (VBAT)
VUSB: J2.A4, J2.A9, J2.B4, J2.B9, PFMF.050.1.1

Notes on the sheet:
USB C connector & ESD protection
Display Type Selector
SD Card
ESP32 C6
Battery Charge Level
External NOR Flash 64MB
SPI ESD Protection Lines
Qwiic / Stemma QT
Test Pads
RTC Module DS3231SN
LDO Voltage Regulator
EPD Power
Environmental Sensor BME688
Li-Po Battery Charging Controller
E-Paper Drive Circuit
E-Paper Display Header
Voltage Supervisor + Reset & Boot / IO Button
Carol-Luca Gasan

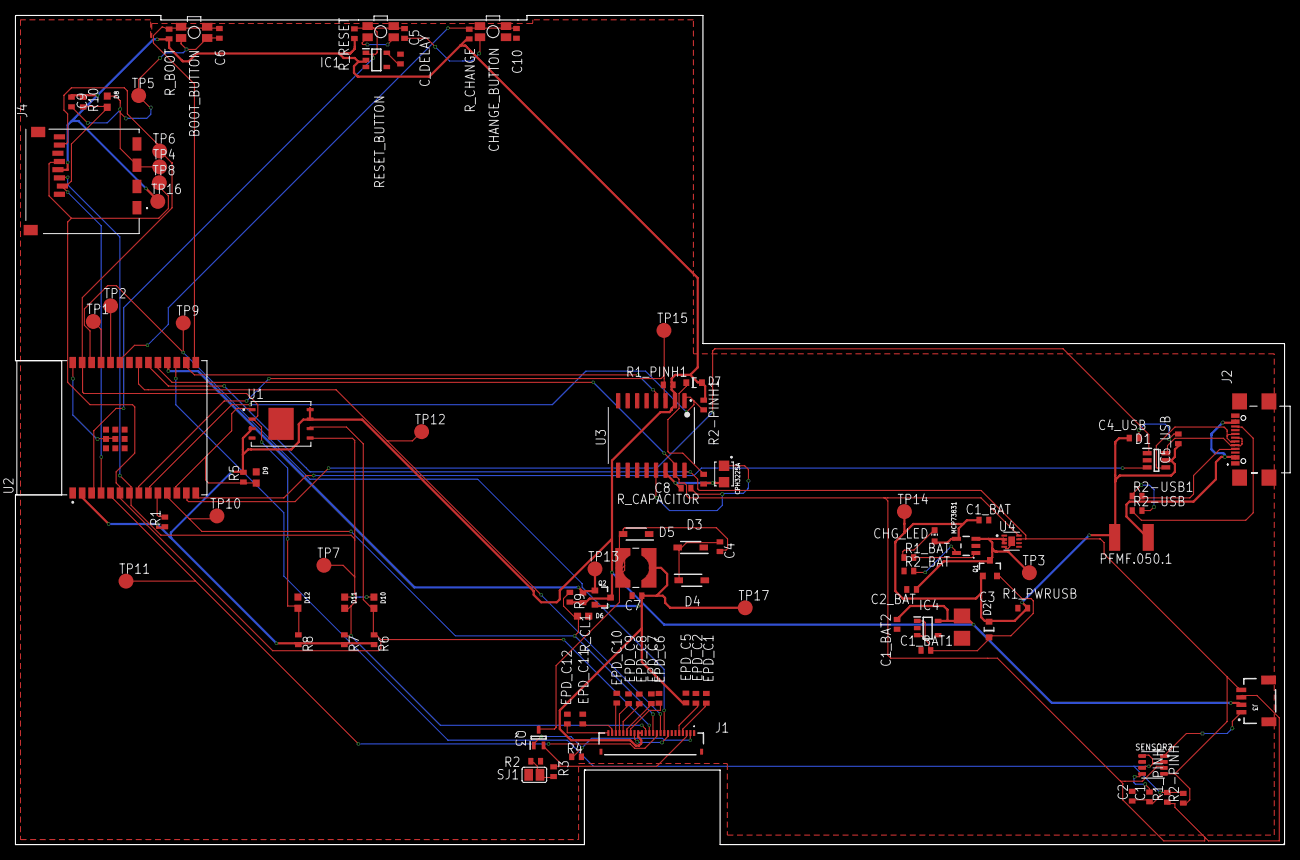
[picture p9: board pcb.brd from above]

Board: 2 copper layers, 170.2 x 111.2 mm, 103 parts (0 on the bottom side), 55 nets.

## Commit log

2025-04-14 addressed all issues
    [pcb.brd]
2025-04-15 another quick one
    [pcb.brd]

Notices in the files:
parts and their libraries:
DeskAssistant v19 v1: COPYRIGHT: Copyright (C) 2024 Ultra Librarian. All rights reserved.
